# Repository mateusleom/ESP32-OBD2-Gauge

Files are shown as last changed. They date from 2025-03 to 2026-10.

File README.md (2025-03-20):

# ESP32-OBD2-Gauge
For complete description, go to original poster (Va&Cob).

In this forks i've made the following changes:
- Removal of selector button, the gauge will boot, connect to ELM327 and go straight to numeri meters. No more menu, DTCs or any kinds of navigation.
- Addition of oil pressure sensor. The code was calibrated to a 150 PSI 0-5V sensor. Although the sensor requires 5vcc, I powered it from 3,3Vcc internal supply of ESP32. It uses pin 27 for ADC. It requires a 2/3 voltage divider in order to read correctly. You must calibrate your pressure sensor with a trusted oil pressure gauge. (https://www.aliexpress.com/item/1005002854614444.html)
- Addition of water level sensor. The sensor accepts 5-25Vcc for supply, but again i used 3.3V from ESP32 and ti worked fine. The sensor used was XKC-25-V wired this way: Brown to ESP 3.3v supply, yellow to esp pin 35, blue and black to gnd.
- Addition of buzzer (https://www.aliexpress.com/item/1005006490431925.html - it must be a 3.3V active buzzer. Passive ones will not work). Uses pins GND and 22.
- 3d printed case for use in subaru's air vent.

- In some screens the colors will become reverse (red will become blue, black will become white, etc). To fix this you must uncomment one of the following lines in \sketch\library modified\TFT_eSPI\User_Setup.h:
           // #define TFT_INVERSION_ON
           // #define TFT_INVERSION_OFF
  One of those lines will fix the issue.

  - Last lines of void setup were modified in order to be able to read from two headers at the same time (7E1 and 7E0) so its possbile to have TCU and ECU information at the same time. Somes formulas where modified, some other lines were also modified.
 
  - I'm not a good coder so don't expect much support as the original poster might be able to do.

Present interface:



Water level sensor support (3d printed in ABS):



Water level sensor in place:



Oil pressure sensor in place:



General Wiring:



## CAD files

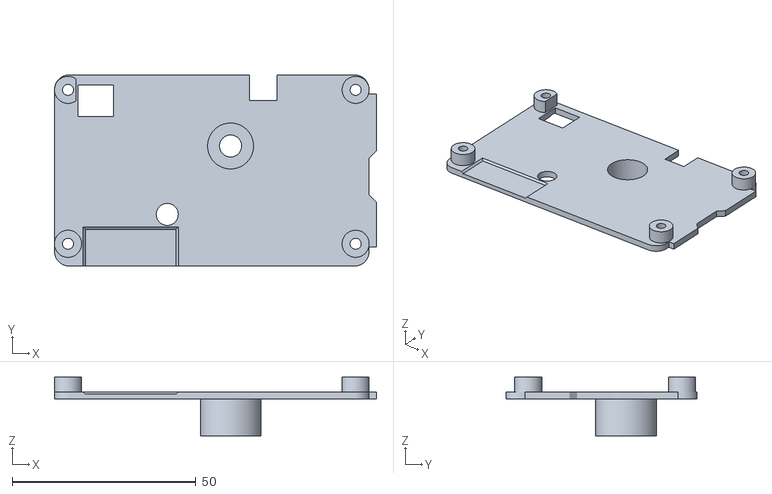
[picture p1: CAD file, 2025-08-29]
3dfiles/Tampa V3.stl
87.6 x 52.0 x 16.0

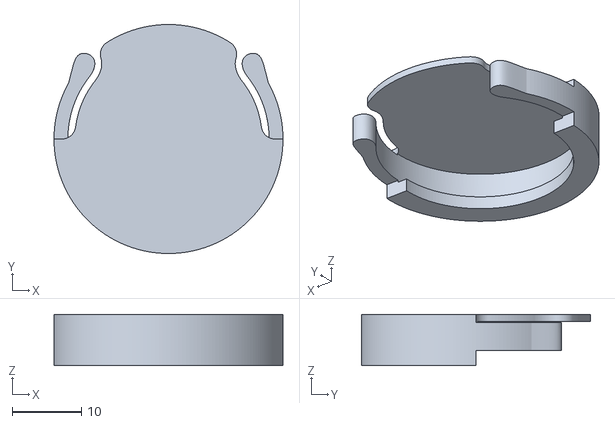
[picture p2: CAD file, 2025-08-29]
3dfiles/Suporte XKC V3.stl
33.0 x 33.0 x 7.40

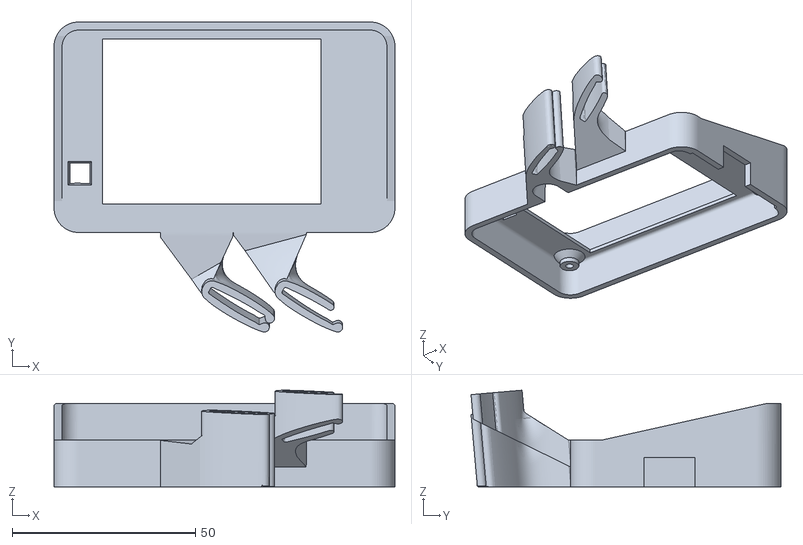
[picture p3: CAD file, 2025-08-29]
3dfiles/Frente V3.stl
93.0 x 84.5 x 26.4

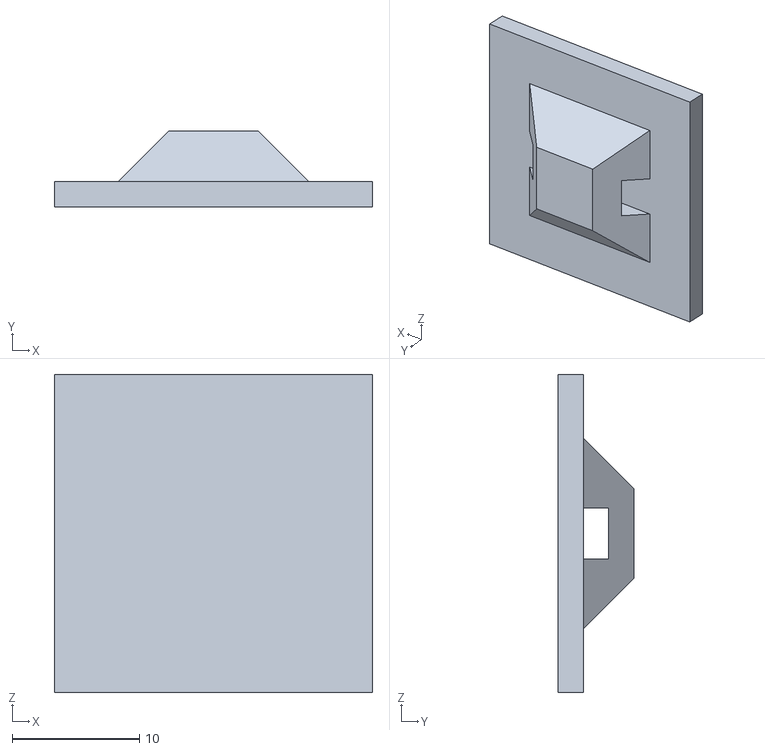
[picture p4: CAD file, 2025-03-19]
3dfiles/fixador.stl
25.0 x 6.00 x 25.0

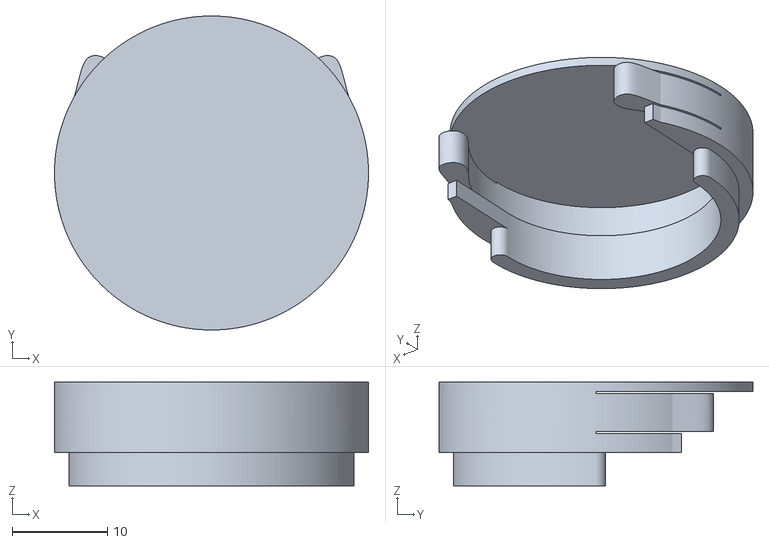
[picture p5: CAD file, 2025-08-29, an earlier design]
3dfiles/Suporte XKC V2.stl
33.0 x 33.0 x 10.9

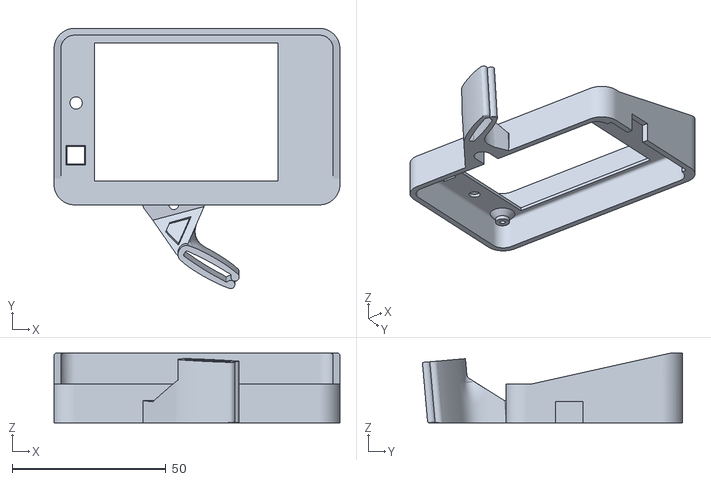
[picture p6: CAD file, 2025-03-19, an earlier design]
3dfiles/Frente V2.stl
93.0 x 84.6 x 22.7

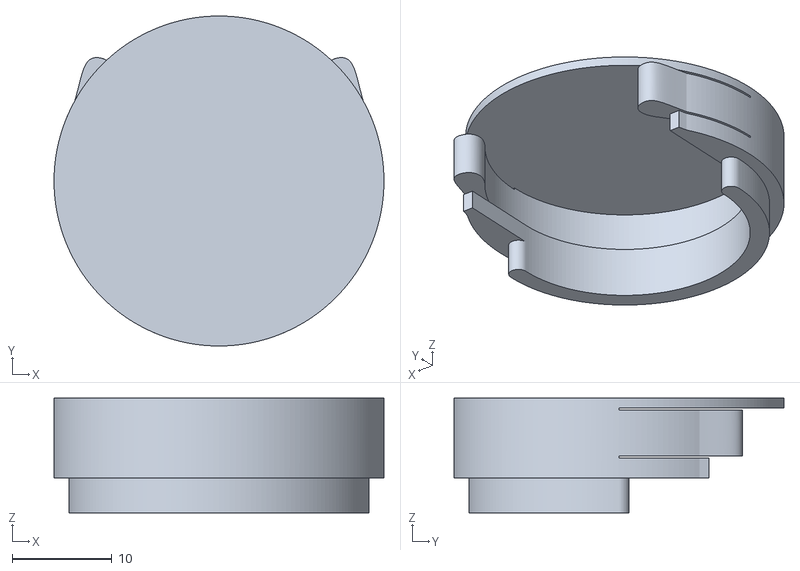
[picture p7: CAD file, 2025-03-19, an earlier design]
3dfiles/Suporte XKC.stl
33.0 x 33.0 x 11.5

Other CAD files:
3dfiles/Tampa V2.stl

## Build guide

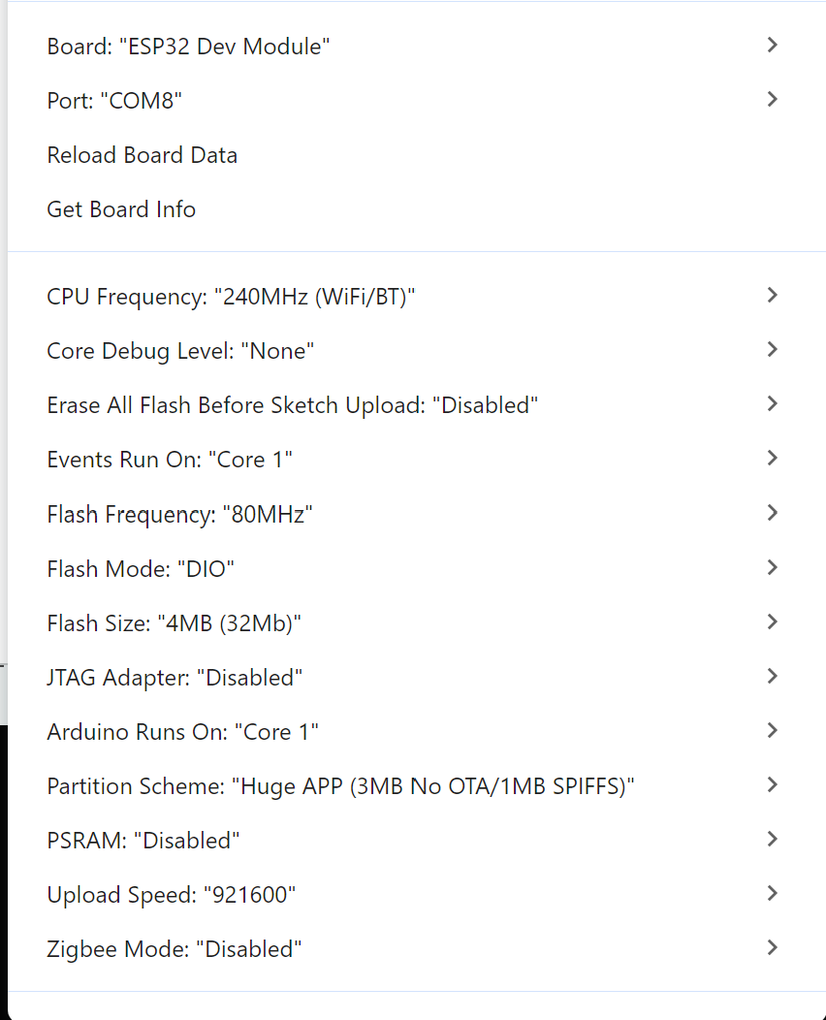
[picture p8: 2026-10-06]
Sketch/ArduinoSetup.png

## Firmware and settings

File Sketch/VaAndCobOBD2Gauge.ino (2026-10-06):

/*=========  Va&Cob OBD2 Gauge ==========
Programmed:  by Ratthanin W.
Hardware:
- Hardware 2.8" TFT ESP32 LVGL https://www.youtube.com/watch?v=d2OXlVcRYrU
Configuration:
- Partition scheme
  option 1 Huge APP 3MB /NO OTA (size is too big)
  option 2 Minimal SPIFFS 1.9MB APP/ 190kB SPIFFS /OTA (for OTA ,must reduce code size)

Important Note:
- New device must flash "gauge_factory_init.ino" first to get it work by checking 'serialno' in pref.
- CPU temp read never work until Bluetooth or Wifi is connected

*/

//--- FLAG SETTING ----- for debugging
//#define TERMINAL //temrinal mode (no gauge)
//#define SERIAL_DEBUG //to show data in serial port
//#define SKIP_CONNECTION //skip elm327 BT connection to view meter
//#define TEST_DTC //test DTC


//Intermal temperature sensor function declaration
#ifdef __cplusplus
extern "C" {
#endif
  uint8_t temprature_sens_read();
#ifdef __cplusplus
}
#endif
uint8_t temprature_sens_read();  //declare intermal temperature sensor functio

//Macro
#define array_length(x) (sizeof(x) / sizeof(x[0]))  //macro to calculate array length

//library load
#include <Preferences.h>  //save permanent data
Preferences pref;         //create preference
#include <BluetoothSerial.h>
#include <TFT_eSPI.h>  //Hardware-specific library


//Pin configuration
//#define SCA_PIN 21//not used same pin with TFT_BL
//#define SCL_PIN 35//not used (avaialable) CAN_TX
#define ADC_PIN 27  //not used (available)  CAN_RX
#define LED_RED_PIN 4
#define LED_GREEN_PIN 16
#define LED_BLUE_PIN 17
#define LDR_PIN 34       //LDR sensor
#define BEEP_PIN 22      //speaker
#define WATER_PIN 35     //speaker
#define BUZZER_PIN 26    //speaker
#define SELECTOR_PIN 35  //push button
// setting PWM properties
#define backlightChannel 0
#define buzzerChannel 2
#include "esp32_compat.h"
//DISPLAY
TFT_eSPI tft = TFT_eSPI();
#define TFT_GREY 0x5AEB


//ELM327 init https://www.elmelectronics.com/wp-content/uploads/2016/07/ELM327DS.pdf
/*const uint8_t elm327InitCount = 13;
const String elm327Init[elm327InitCount] = {
  "ATZ",
  "ATD",
  "ATBRD23",
  "ATSP0",
  "ATAT2",
  "ATL0",
  "ATH0",
  "ATE0",
  "0100",
  "ATSH 7E1",
}; */ //agressive wait response time from ECU
//const String elm327Init[elm327InitCount] = {"ATZ","ATPP0CSV35","ATPP0CON","ATSP0","ATAT2","ATL0","ATH0","ATE0","0100","ATSH07E1"};//agressive wait response time from ECU
const String header[2] = { "ATSH7E0", "ATSH7E1" };

const uint8_t elm327InitCount = 12;
const String elm327Init[elm327InitCount] =  { "ATWS", "ATBRD23", "ATAT2", "ATL0", "ATH0", "ATE0", "ATSP0",};//agressive wait response time from ECU
//const String elm327Init[elm327InitCount] = {"ATZ","ATPP0CSV35","ATPP0CON","ATSP0","ATAT2","ATL0","ATH0","ATE0","0100","ATSH7E0"};//agressive wait response time from ECU


/*------ PIDS total 7 now -------------------
Array data -> { Label , unit, pid, fomula, min, max, ,skip, digit, warn }
label = Pid label show on meter
unit = unit for pid
pid = string pid 0104
formula = formula no to calculate 
min = lowest value
max = highest value
skip = delay reading 0 - 3; 3 = max delay read
digit = want to show digit or not
warn = default warning value
*/

const String pidConfig[8][9] = {
  //[pid][data]
  //{ Label     , unit,    pid,  fomula, min,    max, ,skip, digit, warn }
  { "CVT Temp"   , "`C" , "2210D2", "5", "60" , "120" , "3", "0", "99" },   // 0 -> CVT Temp (Linha 1 Esquerda)
  { "Coolant"    , "`C" , "0105"  , "1", "60" , "120" , "1", "0", "105" },  // 1 -> Coolant (Linha 1 Direita)
  { "Short Trim" , "%"  , "0106"  , "6", "-30", "30"  , "0", "1", "760" },  // 2 -> Short Trim (Linha 2 Esquerda)
  { "AFR"        , "A/F", "0134"  , "2", "0"  , "2"   , "1", "2", "200" },  // 3 -> AFR (Linha 2 Centro)
  { "Long Trim"  , "%"  , "0107"  , "6", "-30", "30"  , "0", "1", "760" },  // 4 -> Long Trim (Linha 2 Direita)
  { "Water Level", "IO" , "013C"  , "8", "0"  , "101" , "2", "0", "60" },   // 5 -> Water Level (Linha 3 Esquerda)
  { "Oil Press"  , "bar", "0105"  , "7", "0"  , "10"  , "0", "1", "200" },  // 6 -> Oil Press (Linha 3 Direita)
  { "ENG SPD"    , "rpm", "010C"  , "3", "0"  , "5000", "3", "0", "9000" }  // 7 -> Engine monitor
};

//hold warning value
String warningValue[8] = { "99", "105", "760", "200", "760", "60", "200", "9000" };

/*  User configuration here to change display 
    Linha 1: CVT Temp (esq), Coolant (dir)
    Linha 2: Short Trim (esq), AFR (centro), Long Trim (dir)
    Linha 3: Water Level (esq), Oil Press (dir)
*/
const uint8_t pidInCell[4][8] = {
  { 0, 1, 2, 3, 4, 5, 6, 7 },  //layout 0 (unused)
  { 0, 1, 2, 3, 4, 5, 6, 7 },  //layout 1 (unused)
  { 0, 1, 2, 3, 4, 5, 6, 7 },  //layout 2 -> 7 medidores numericos (3 na linha 2)
  { 0, 1, 2, 3, 4, 5, 6, 7 },  //layout 3 -> 7 medidores de arco (3 na linha 2)
};
// User configuration here to change display  >

/*---------------------------*/
//if NO DATA value will set to 0 to skip reading
uint8_t layout = 2;                                   //pidInCelltype 0-4 EEPROM 0x00
const uint8_t max_layout = array_length(pidInCell);   //total 5 type of display page
uint8_t pidIndex = 0;                                 //point to PID List
const uint8_t maxpidIndex = array_length(pidConfig);  //total 7 pids in picConfig
bool prompt = false;                                  //bt elm ready flag
bool skip = false;                                    //pid skip flag
uint8_t A = 0;                                        //get A
uint8_t B = 0;                                        //get B


//Global variable
const uint32_t SLEEP_DURATION = 180 * 1000000;                         //180 sec* us = 3 min
String line[12] = { "", "", "", "", "", "", "", "", "", "", "", "" };  //buffer for each line in terminal function
bool dim = false;                                                      //back light dim flag
const uint8_t LIGHT_LEVEL = 40;                                        //backlight control by light level Higher = darker light
long runtime = 0;                                                      //to check FPS
long holdtime = 0;                                                     //hold time for button pressed check
const String compile_date = __DATE__ " - " __TIME__;                   //get built date and time
bool press = false;                                                    // button press flag
bool showsystem = false;                                               //show fps and temp EEPROM 0x01
uint8_t pidRead = 0;                                                   //counter that hold number of pids been read to check pid/sec
String serial_no = "";                                                 //keep serial no.

//CPU Temp
const uint8_t tempOverheat = 60;       //max operating cpu temp 60c
const int8_t factoryTempOffset = -50;  //default offset adjustment temp up to each tested esp32 max at -50
float tempRead = 0.0;                  //current reading cpu temp
int8_t tempOffset = 0;                 //offset adjustment temp up to each tested esp32
uint8_t temp_read_delay = 0;           //hold delay counter to read temp
uint8_t temp_overheat_count = 0;       //counter to read continuiosly overheat

//BLUETOOTH
String bt_message = "";                                                     //bluetooth message buffer
String se_message = "";                                                     //serial port message buffer
String deviceName[8] = { "", "", "", "", "", "", "", "" };                  //discoveryBT name
String deviceAddr[8] = { "", "", "", "", "", "", "", "" };                  //discover BT addr
uint8_t btDeviceCount = 0;                                                  //discovered bluetooth devices counter
#define BT_DISCOVER_TIME 5000                                               //bluetooth discoery time
esp_bd_addr_t client_addr = { 0x00, 0x00, 0x00, 0x00, 0x00, 0x00 };         //obdII mac addr
esp_bd_addr_t recent_client_addr = { 0x00, 0x00, 0x00, 0x00, 0x00, 0x00 };  //keep last btaddr in RTC memory
const String client_name = "OBDII";                                         //adaptor name to search
esp_spp_sec_t sec_mask = ESP_SPP_SEC_NONE;                                  // or ESP_SPP_SEC_ENCRYPT|ESP_SPP_SEC_AUTHENTICATE to request pincode confirmation
esp_spp_role_t role = ESP_SPP_ROLE_SLAVE;                                   // or ESP_SPP_ROLE_MASTER
bool foundOBD2 = true;
BluetoothSerial BTSerial;  //bluetooth serial device

//---- Include Header File ---
#include "image.h"
#include "touchscreen.h"

/*----------- global function ---------*/

//------------------------------------------------------------------------------------------
void checkCPUTemp() {  //temperature can read only when BT or Wifi Connected
/*temp_read_delay++; 
  if ((temp_read_delay >= 50) && (foundOBD2)) {//delay loop 50 then read temp, avoid error eading
    temp_read_delay = 0;
    uint8_t temperature = temprature_sens_read();//read internal temp sensor
    tempRead = (temperature -32)/1.8 + tempOffset;//change unit F to C
    #ifdef SERIAL_DEBUG
    Serial.print(tempRead,1);   //print Celsius temperature and tab
    Serial.println("°c");
    #endif 
    //read 10 times to confirm it's really overtemp.
    if (tempRead >= tempOverheat) temp_overheat_count++;//count overheat time
    else temp_overheat_count = 0;//reset
    if (temp_overheat_count > 10) {//overheat read more than 10 times.
      Serial.printf("CPU Overheat Shutdown at %d°C\n",tempOverheat);
      tft.fillRectVGradient(0, 0, 320, 240, TFT_RED, TFT_BLACK);
      tft.pushImage(127,5,64,64,overheat,TFT_RED);//show sdcard icon
      tft.setTextColor(TFT_WHITE);
      tft.drawCentreString("CPU Overheat Shutdown!",159,75,4);
      tft.setTextColor(TFT_WHITE,TFT_BLUE);
      tft.drawCentreString("Auto-restart within 3 minutes",159,140,4);
      tft.drawCentreString("OR",159,170,4);
      tft.drawCentreString("Press button to restart",159,200,4);
      ledcWriteTone(buzzerChannel, 1500);
      delay(5000);
      ledcWriteTone(buzzerChannel, 0);
      BTSerial.disconnect();//disconnect bluetooth
      tft.fillScreen(TFT_BLACK);
      tft.writecommand(0x10); //TFT sleep
      //enter deep sleep
      esp_sleep_enable_timer_wakeup(SLEEP_DURATION);//sleep timer 3 min
      esp_sleep_enable_ext0_wakeup(GPIO_NUM_27,LOW); //wake when button pressed
      esp_deep_sleep_start();  //sleep shutdown backlight auto off with esp32
    }//if temp_overheat_coun
  }//if temp_read_delay
*/}//check CPU Temp
/*------------------*/

//TERMINAL terminal for debugging display text
void Terminal(String texts, uint16_t x, uint16_t y, uint16_t w, uint16_t h) {
  uint8_t max_line = round((h - y) / 16.0);
  tft.fillRect(x, y, x + w, y + h, TFT_BLACK);
  tft.setTextColor(TFT_WHITE);
  for (uint8_t i = 0; i < max_line; i++) {
    if (i <= max_line - 2) {
      line[i] = line[i + 1];
    } else {
      line[i] = texts;
    }
    tft.drawString(line[i], x, i * 20 + y, 2);
  }                 //for
  bt_message = "";  //reset bt message
}
/*------------------*/
/*
void checkGenuine() {//check if genuine obd2 gauge - must flash "gauge_factory_init.ino" first
//security {serialno: "V&C-OBDII-001"}
  pref.begin("security", true);//read only
  serial_no = pref.getString("serialno","");//if no serial no, then empty
  Serial.print(F("Serial No: "));
  if (serial_no == "") {
    tft.setTextColor(TFT_WHITE,TFT_RED);
    tft.drawString("Not genuine Va&Cob Gauge!",0,115,4);
    Serial.println(F("Not genuine Va&Cob Gauge!"));
    while(true) {//beep
      ledcWriteTone(buzzerChannel,2000);
      digitalWrite(LED_RED_PIN, LOW);//red on
      delay(500);
      ledcWriteTone(buzzerChannel,0);
      digitalWrite(LED_RED_PIN, HIGH);//red off
      delay(500);
    }
  } else {
    Serial.println(serial_no);//print serial no
    pref.end();
  }
}
//----------------------------------------------
*/
//---- Include Header File --------------------
//#include "image.h"
#include "bluetooth.h"
#include "meter.h"
#include "config.h"

//---- Inicializacao do ELM327 -----------------
void initELM327() {
  Terminal("Initializing ELM327...", 0, 48, 320, 191);
  bt_message = "";
  for (uint8_t initIndex = 0; initIndex < elm327InitCount; initIndex++) {  //send init ELM327 AT command
    BTSerial.print(elm327Init[initIndex] + "\r");
    if (initIndex == elm327InitCount - 1) delay(2000);  //wait for protocol search
    else delay(100);
    while (BTSerial.available() > 0) {
      char incomingChar = BTSerial.read();
      if (incomingChar == '>') {  //check prompt
        BTSerial.flush();         //clear buffer
#ifdef SERIAL_DEBUG
        Serial.println(bt_message);
#endif
#ifdef TERMINAL
        Terminal(bt_message, 0, 48, 320, 191);
#endif
        if (initIndex == 1) BTSerial.print("\r");  //ATBRD23 response
        bt_message = "";
      } else {
        bt_message.concat(incomingChar);
      }
    }  //while
  }    //for
}

//---- Rotina de Monitoramento e Reconexao Bluetooth ----
void checkConnection() {
  static unsigned long lastCheck = 0;
  if (millis() - lastCheck < 1000) return;  //verifica apenas 1 vez por segundo
  lastCheck = millis();

  // Testa EXCLUSIVAMENTE se a conexao Bluetooth esta ativa
  if (!BTSerial.connected()) {
    Serial.println(F("\n[BT] Conexao Bluetooth perdida!"));

    // Alerta visual no topo da tela
    tft.fillRect(0, 0, 320, 26, TFT_RED);
    tft.setTextColor(TFT_WHITE, TFT_RED);
    tft.drawCentreString("BT DESCONECTADO - Reconectando...", 160, 4, 2);

    BTSerial.disconnect();
    delay(300);

    // Tenta reconexao rapida ao ultimo dispositivo conhecido
    connectLastOBDII();

    if (foundOBD2 && BTSerial.connected()) {
      Serial.println(F("[BT] Reconectado com sucesso!"));
      initELM327();
      initScreen();
      // Reseta variaveis e contadores
      for (uint8_t i = 0; i < maxpidIndex; i++) old_data[i] = 0.0;
      engine_off_count = 0;
      BTSerial.flush();
      while (BTSerial.available() > 0) BTSerial.read();
      bt_message = "";
      skip = false;
      pidIndex = 0;
      prompt = true;
    } else {
      // Se a reconexao imediata falhar, reiniciar o ESP32 e a opcao mais leve e confiavel
      Serial.println(F("[BT] Falha ao reconectar. Reiniciando ESP32..."));
      tft.fillScreen(TFT_BLACK);
      tft.setTextColor(TFT_RED);
      tft.drawCentreString("Bluetooth Perdido!", 160, 90, 4);
      tft.setTextColor(TFT_WHITE);
      tft.drawCentreString("Reiniciando ESP32...", 160, 135, 2);
      delay(1000);
      ESP.restart();
    }
  }
}
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
void loop() {
  // 1. Verifica se o Bluetooth esta ativo
  checkConnection();

  // 2. Touch screen: alternar entre tela 2 (medidores numericos) e tela 3 (medidores de arco)
  static bool wasTouched = false;
  static unsigned long lastTouchTime = 0;

  if (ts.touched()) {
    if (!wasTouched && (millis() - lastTouchTime > 400)) {
      wasTouched = true;
      lastTouchTime = millis();

      // Alterna entre tela 2 e tela 3
      if (layout == 2) {
        layout = 3;
      } else {
        layout = 2;
      }
      pref.putUShort("layout", layout);

      ledcWriteTone(buzzerChannel, 5000);  // som de clique
      delay(10);
      ledcWriteTone(buzzerChannel, 0);

      initScreen();  // recarrega a tela selecionada

      // reset variaveis de leitura
      for (uint8_t i = 0; i < maxpidIndex; i++) old_data[i] = 0.0;
      engine_off_count = 0;
      BTSerial.flush();
      while (BTSerial.available() > 0) {
        BTSerial.read();
      }
      bt_message = "";
      skip = false;
      pidIndex = maxpidIndex - 1;
      prompt = true;
    }
  } else {
    wasTouched = false;
  }

  //----------------------
  //BLUETOOTH read
  while (BTSerial.available() > 0) {
    char incomingChar = BTSerial.read();
    if (incomingChar == '>') {  //check prompt
      BTSerial.flush();         //clear tx
#ifdef SERIAL_DEBUG
      Serial.println(bt_message);
      //Serial.println("testeloop)");
#endif
#ifdef TERMINAL  //for degbugging
      getAB(bt_message);
      Terminal(bt_message + "->" + String(A) + "," + String(B), 0, 48, 320, 191);
#endif
      prompt = true;  //pid response ready to calculate & display
    } else {
      bt_message.concat(incomingChar);  //keep elm327 respond
    }
  }
  //----------------------
  //SERIAL PORT read
  if (Serial.available() > 0) {
    char incomingChar = Serial.read();
    //check CR/NL
    if ((incomingChar != '\r') && (incomingChar != '\n')) {
      se_message.concat(incomingChar);
      //Serial.print(incomingChar,HEX);
    } else {

      if (se_message != "") {
#ifdef TERMINAL
        Terminal(se_message, 0, 48, 320, 191);  //display terminal
#endif
        BTSerial.print(se_message + "\r");
        se_message = "";
        Serial.flush();
      }  //if se_message

    }  //else if incomingChar
  }    //if Serial.available

  //Send another PID to elm327
  if (prompt) {      //> ELM327 ready! -> request next PID
    prompt = false;  //no prompt from ELM327
    checkCPUTemp();  //check temperature.
    if (!skip) {
      updateMeter(pidIndex, bt_message);  //update meter screen
      pidRead++;                          //for calculate pid/s
    }
    pidIndex++;  //point to next pid
    if (pidIndex >= maxpidIndex) {
      pidIndex = 0;      //back to pid 0
      autoDim();         //auto backlight handle
      if (showsystem) {  //aqui mostra alguma informação sem utilidade
        String status = String(pidRead * 1000.0 / (millis() - runtime), 0) + " p/s " + String(tempRead, 1) + "`c";
        tft.setTextColor(TFT_YELLOW, TFT_BLACK);
        tft.drawCentreString(status.c_str(), 159, 0, 2);
        runtime = millis();
      }             //if showsystem
      pidRead = 0;  //reset pid read counter
    }
    if (pidCurrentSkip[pidIndex] <= 0) {                 //end of skip loop , go next index
      pidCurrentSkip[pidIndex] = pidReadSkip[pidIndex];  //read max delay loop to current
      skip = false;

      if(pidList[pidIndex]=="2210D2"){    //troca os headers de acordo com pid 2210D2
        BTSerial.print(header[1] + "\r");
        delay(100);
        BTSerial.print(pidList[pidIndex] + "\r");              //send PID request
        delay(100);
        BTSerial.print(header[0] + "\r");
        delay(100);
      }else{
        BTSerial.print(pidList[pidIndex] + "\r");                 //send PID request
        //delay(100);
      }
      
      //BTSerial.print(pidList[pidIndex] + "\r");                 //send PID request
      
    } else {                                                    //skip sending request
      pidCurrentSkip[pidIndex] = pidCurrentSkip[pidIndex] - 1;  //decrese loop count
      prompt = true;
      skip = true;
    }  //else

  }  //if prompt

  /*------------------*/
}  // loop

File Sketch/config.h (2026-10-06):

/* "config.h"
this header file is for configuration menu
*/
//freeRTOS multi tasking
#include <freertos/FreeRTOS.h>
#include <freertos/task.h>

#include <FS.h>
#include <SD.h>
#include <SPIFFS.h>

/*------------ SOUND EFFECT ----------*/
void beepbeep() { //2 shot beep
  ledcWriteTone(buzzerChannel, 2000);
  delay(50);
  ledcWriteTone(buzzerChannel, 0);
  delay(50);
  ledcWriteTone(buzzerChannel, 2000);
  delay(50);
  ledcWriteTone(buzzerChannel, 0);
}              
void beep() { 
  ledcWriteTone(buzzerChannel, 2000);
  delay(500);
  ledcWriteTone(buzzerChannel, 0);
}  
void clickSound() {
  ledcWriteTone(buzzerChannel, 5000);
  delay(5);
  ledcWriteTone(buzzerChannel, 0);
} 
#include "elm327.h"// read VIN function

#define mypic_filename "/mypic.jpg"//mypic file
#define FORMAT_SPIFFS_IF_FAILED true//format if no spiffs

//configuration menu 
const String menuList[8] = {
  "Show pid/s & CPU Temp",//toggle show system
  "Load my pic 320x240 px",//load user own pic
  "Update firmware",//update new firmware
  "Warning setting",//setting warning parameter (warning data, offset temp)
  "DTCs",//dtc engine 
  "Auto-off",//auto turn off
  "About",//about
  "Exit"
  }; 
const uint8_t maxMenu = array_length(menuList);//length of menu list

//menu list for warning setting
const String parameterList[8][2] = {
    {"CPU Overheat Temperature "+String(tempOverheat)+"`c ,offset "," `c  "},
    {"- Engine Load"," %  "},
    {"- Coolant Temperature"," `c  "},
    {"- Manifold Air Pressure"," psi "},
    {"- Engine Speed"," rpm "},
    {"- PCM Voltage"," volt"},
    {"- Engine Oil Temperature"," `c  "},
    {"- Transmission Fluid Temperature"," `c  "}
  };  

//increasement and decreasement of each PID  
const int pidWarnStep[8] = {1,5,1,5,500,1,1,1};

//Sprites
TFT_eSprite car = TFT_eSprite(&tft);
TFT_eSprite bk = TFT_eSprite(&tft);
TFT_eSprite pole = TFT_eSprite(&tft);
TFT_eSprite fence = TFT_eSprite(&tft);
//----------------------------
void animation() {//start field effect
//sprite variable
#define BK_HEIGHT 80
#define BK_WIDTH 235
  uint8_t cur_x = 68;
  uint8_t cur_y = 10;
  uint8_t dash_x = 20;
  int16_t tag_x = 235;
  int16_t fence_x = 0;
  uint8_t ani_speed = 2;

//create spirtes
  bk.createSprite(BK_WIDTH,BK_HEIGHT);

  car.createSprite(CAR_WIDTH,CAR_HEIGHT);//image size 114x50
  car.setSwapBytes(true);
  car.pushImage(0,0,CAR_WIDTH,CAR_HEIGHT,futurecar);//image size 114x50

  pole.createSprite(POLE_WIDTH,POLE_HEIGHT);
  pole.setSwapBytes(true);
  pole.pushImage(0,0,POLE_WIDTH,POLE_HEIGHT,pole1);

  fence.createSprite(FENCE_WIDTH,FENCE_HEIGHT);
  fence.setSwapBytes(true);
  fence.pushImage(0,0,FENCE_WIDTH,FENCE_HEIGHT,fence1);
//-------------------------------
  tft.fillScreen(TFT_BLACK);//clear screen  
//draw QRCode
  tft.drawBitmap(0, 159, qrcode, QRCODE_WIDTH, QRCODE_HEIGHT, TFT_WHITE);
//draw text
  tft.setTextColor(TFT_WHITE);
  tft.drawString(">MAP/ENG LOAD/ECT/EOT/TFT/ENG SPD/PCM Volt",0,40,2);
  tft.drawString(">Warning, Automatic Dim/OnOff/O็verheat Shutdown",0,60,2);
  tft.drawString(">Read DTC Code & Clear MIL Status",0,80,2);
  tft.drawString("* FW-\"VaandCobOBD2Gauge.bin\" * Image-\"mypic.jpg\"",0,100,2);
  tft.drawString("* Facebook : www.facebook.com/vaandcob",0,120,2);
  tft.setTextColor(TFT_YELLOW);
  tft.drawString("  [ Manual ] ----------------[ Press button to exit ]",0,140,2);
  tft.setTextColor(TFT_CYAN); 
  String txt = "[ "+serial_no+" ] BUILD : "+compile_date;
  tft.drawString(txt,0,0,2);
  //get VIN
  getPID("ATE0");//force echo off
  txt = "VIN :  " + getVIN(getPID("0902"));
  tft.setTextColor(TFT_GREENYELLOW); 
  tft.drawString(txt,0,20,2);

  bk.setTextColor(TFT_BLACK,TFT_ORANGE);
//loop draw Animation
  while (digitalRead(SELECTOR_PIN) == HIGH) {//exit if press button

  //draw road
    bk.fillSprite(0x4228);//draw road
    bk.fillRect(0,0,235,16,TFT_LIGHTGREY);
    bk.fillRect(0,16,235,3,0x8430);

  //draw dash line
    for(int16_t i = 0; i < 5; i++) {
                     //speed     //space //posY //length
   // bk.drawFastHLine(dash_x         +(40 * i), 20,10,TFT_WHITE);//far end dash line
      bk.drawFastHLine((dash_x-20)*1.5+(60 * i),45,15,TFT_WHITE);//middle dash line
   // bk.drawFastHLine((dash_x-40)*2.0+(80 * i),79,20,TFT_WHITE);//nearest dash line
    }
    dash_x = dash_x - ani_speed;
    if (dash_x <= 0 ) dash_x = 40;

  //draw traffic 
    tag_x = tag_x - ani_speed;
    if (tag_x <= -80) tag_x = 235;
    //bk.setTextColor(random(0xffff));
    bk.drawString("< Thank You >",tag_x,0,2);//draw billboard

  //draw car
    int8_t move = random(-1,2);
    cur_x = cur_x + move;
    move = random(-1,2);
    cur_y = cur_y + move;
    if (cur_x > 235-CAR_WIDTH) cur_x = 235-CAR_WIDTH;
    if (cur_x < 1) cur_x = 1;
    if (cur_y < 1) cur_y = 1;
    if (cur_y > 79-CAR_HEIGHT) cur_y = 79-CAR_HEIGHT;
    car.pushToSprite(&bk,cur_x,cur_y,TFT_BLACK);//put car into bk, white color as transparent
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
